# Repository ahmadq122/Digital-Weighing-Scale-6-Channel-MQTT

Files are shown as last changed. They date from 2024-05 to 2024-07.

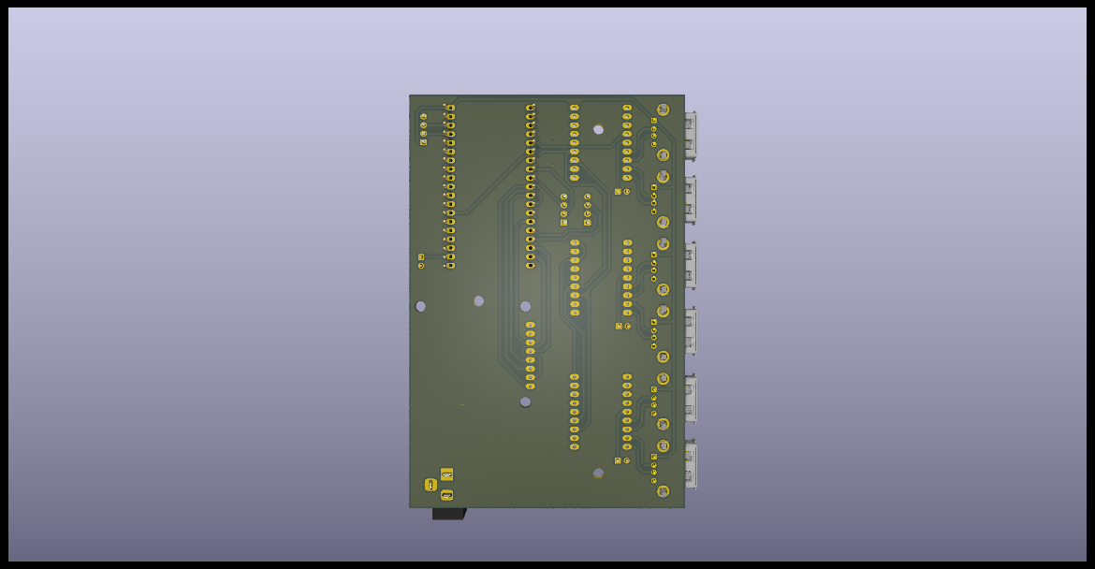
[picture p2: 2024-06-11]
kicad/kicad-weight-scale-6-ch/png/kicad-weight-scale-6-ch_bot.png

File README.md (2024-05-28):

# Digital-Weighing-Scale-Board-6-Channels-MQTT
The board uses ESP32 Dev Board as the microcontroller with Nextion 3.2" Enhanced LCD Touch as a User Interface, made in portable form, and easy to use. Real Time Operating System (FreeRTOS) was applied to get better code structure and device performance. Weighing can be performed on 6 different objects at the same time, with adjustable maximum weighing on each channel. Use 3 pcs of IC ADS1232 as an Analog to Digital Converter. Calibration sensor feature available, with a maximum of 8 calibration points. 3 data logging types are available, which are Local via Micro SD card, Serial UART, and logging through MQTT Protocol.

The code programming is done in IDE: Visual Studio Code - Platform IO, Framework: Arduino

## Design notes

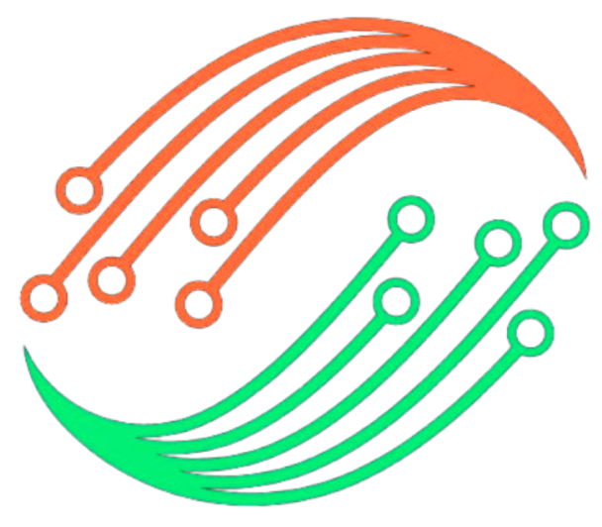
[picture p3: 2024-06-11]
kicad/kicad-weight-scale-6-ch-rev_1.1-1.0/png/kieworks_eng.png

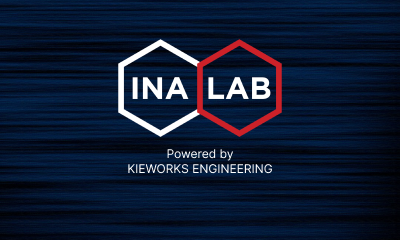
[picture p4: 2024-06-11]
hmi/start screen.png

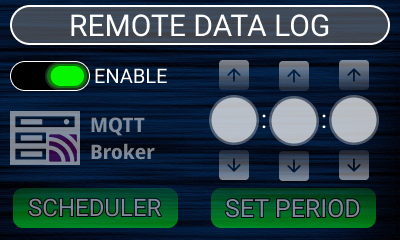
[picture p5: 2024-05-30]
hmi/Remote logger pressed.png

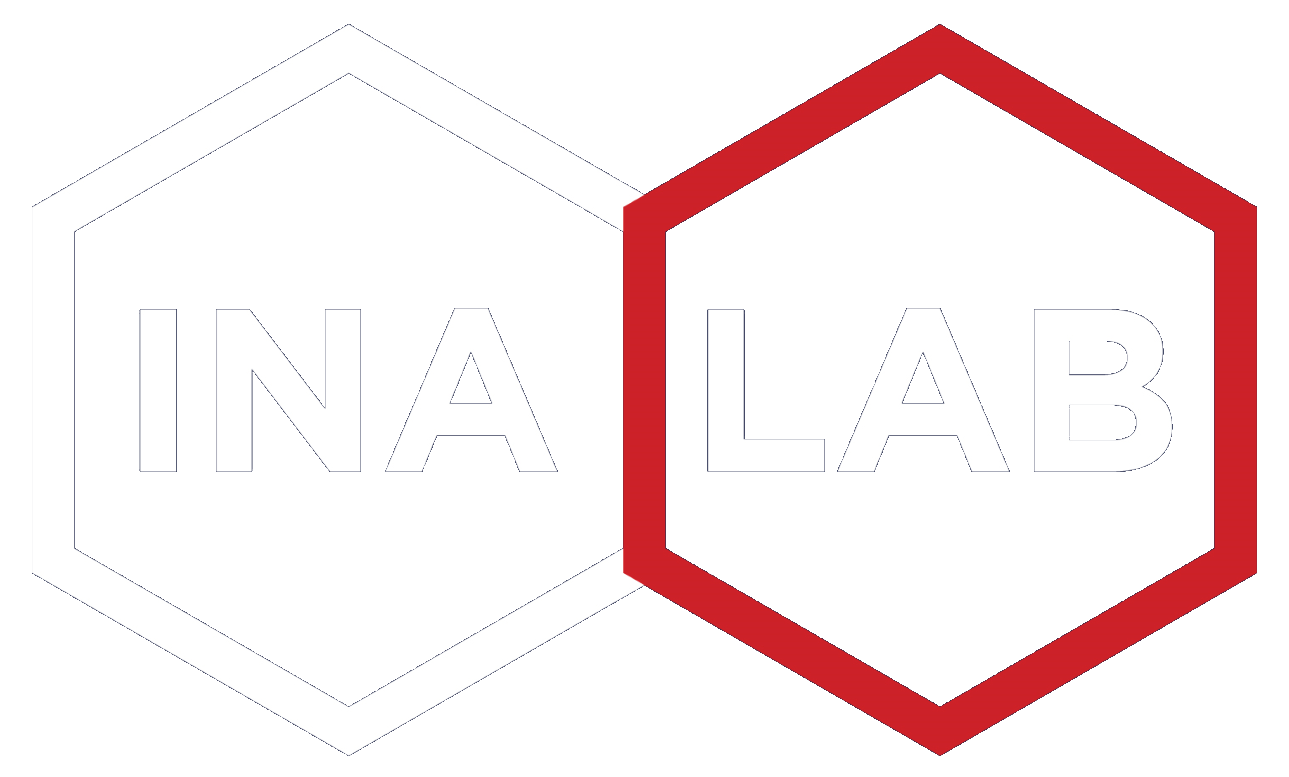
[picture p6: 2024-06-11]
kicad/kicad-weight-scale-6-ch/png/INALAB-full.png

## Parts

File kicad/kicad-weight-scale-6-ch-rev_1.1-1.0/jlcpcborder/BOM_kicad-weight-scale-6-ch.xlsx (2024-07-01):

ID | Name | Designator | Footprint | Quantity | Manufacturer Part | Manufacturer | Supplier | Supplier Part | Price | Remarks
1 | 330uF | C1 | CAP-SMD_BD6.3-L6.6-W6.6-LS7.2-FD | 1 | RST330UF10V027 | KNSCHA(科尼盛) | LCSC | C4747980 | 0.033
2 | SS14_C2986110 | D2,D1 | SMA_L4.3-W2.6-LS5.1-RD | 2 | SS14 | GOODWORK(固得沃克) | LCSC | C2986110 | 0.01
3 | DS1021-1X2SF11-B | J6,J8,J7 | HDR-TH_2P-P2.54-V-M | 3 | DS1021-1x2SF11-B | CONNFLY | LCSC | C7430358 | 0.009
4 | KH-2.54FH-1X19P-H8.5 | U3 | HDR-TH_19P-P2.54-V-F | 2 | KH-2.54FH-1X19P-H8.5 | kinghelm(金航标) | LCSC | C2932678 | 0.145 | Pair Installation
5 | JTJ-USB-AF-08 | P2,P4,P5,P6,P1,P3 | USB-A-TH__USB-AF-90 | 6 | 902-131A1011D10100 | 精拓金 | LCSC | C2345 | 0.046
6 | 47k | R4,R3 | R0805 | 2 | RC0805JR-0747KL | YAGEO(国巨) | LCSC | C131051 | 0.002
7 | DS1023-1X9SF11 | U6,U4,U2 | HDR-TH_9P-P2.54-V-F-1 | 6 | DS1023-1x9SF11 | CONNFLY | LCSC | C7509520 | 0.059 | Pair Installation
8 | 27k | R1 | R0805 | 1 | CR0805J80273G | LIZ(丽智电子) | LCSC | C101982 | 0.003
9 | Serial2 | J5 | CONN-TH_4P-P2.50_XH-4A | 1 | XH-4A | BOOMELE(博穆精密) | LCSC | C37815 | 0.012
10 | Serial1 | J4 | CONN-TH_4P-P2.50_XH-4A | 1 | XH-4A | BOOMELE(博穆精密) | LCSC | C37815 | 0.012
11 | LM2596MDT-5.0/TR | U1 | TO-263-5_L10.2-W8.9-P1.70-BR | 1 | LM2596S-5.0 | UMW(友台半导体) | LCSC | C347421 | 0.492
12 | Header-Female-2.54_1x8 | U5 | HDR-TH_8P-P2.54-V-F-1 | 1 | 2.54-1*8P母环保 | BOOMELE(博穆精密) | LCSC | C27438 | 0.074
13 | Reset | J2 | HDR-TH_2P-P2.54-V-M | 1 | DS1021-1x2SF11-B | CONNFLY | LCSC | C7430358 | 0.009
14 | 33uH | L1 | IND-SMD_L12.0-W12.0_CDRH125L125NP-470MC | 1 | PSPHAQ127-330M | PROD(谱罗德) | LCSC | C2983067 | 0.211
15 | Serial | J3 | CONN-TH_4P-P2.50_XH-4A | 1 | XH-4A | BOOMELE(博穆精密) | LCSC | C37815 | 0.012
16 | 100k | R2 | R0805 | 1 | PTFR0805B100KP9 | RESI(开步睿思) | LCSC | C478884 | 0.126
17 | 220uF | C2 | CAP-SMD_BD6.3-L6.6-W6.6-FD | 1 | 189RV0019 | KNSCHA(科尼盛) | LCSC | C7471881 | 0.087
18 | DC-005-20A | J1 | DC-IN-TH_DC005 | 1 | DC-005-20A | 韩国韩荣 | LCSC | C130239 | 0.095

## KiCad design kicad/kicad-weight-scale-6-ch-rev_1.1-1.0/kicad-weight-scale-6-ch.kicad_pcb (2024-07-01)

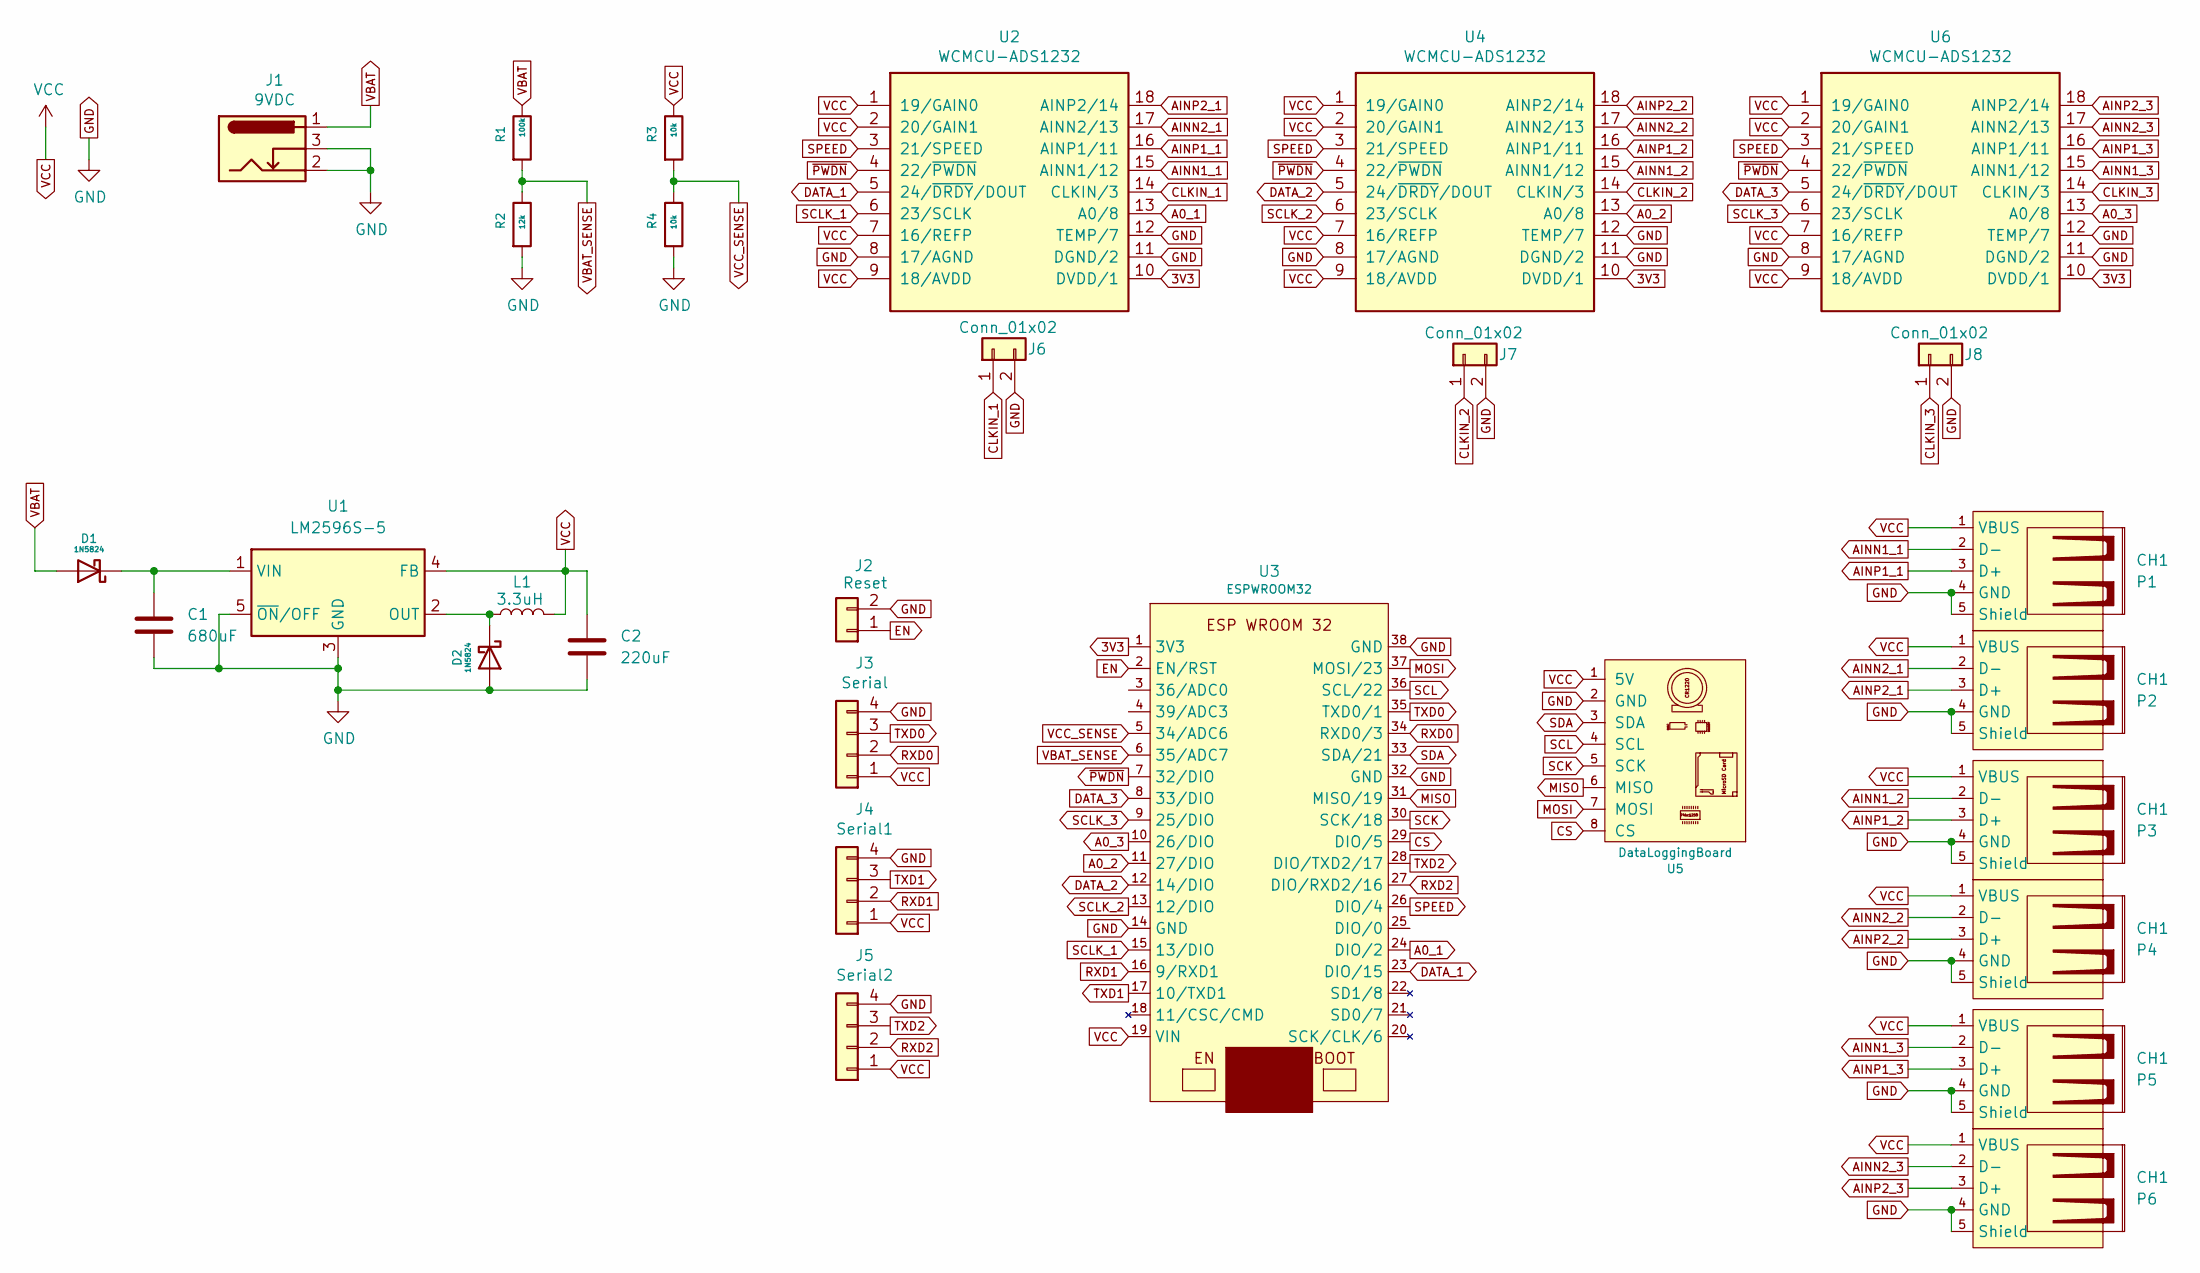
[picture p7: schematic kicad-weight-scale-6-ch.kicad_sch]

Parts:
C1: 680uF; CP_Elec_6.3x9.9
C2: 220uF; CP_Elec_6.3x9.9
D1, D2: 1N5824; D_SMA
J1: 9VDC; BarrelJack_Horizontal
J2: Reset; PinHeader_1x02_P2.54mm_Vertical
J3: Serial; JST_XH_B4B-XH-A_1x04_P2.50mm_Vertical
J4: Serial1; JST_XH_B4B-XH-A_1x04_P2.50mm_Vertical
J5: Serial2; JST_XH_B4B-XH-A_1x04_P2.50mm_Vertical
J6, J7, J8: Conn_01x02; PinHeader_1x02_P2.54mm_Vertical
L1: 3.3uH; L_12x12mm_H4.5mm
P1, P2, P3, P4, P5, P6: CH1; USB_A_CONNFLY_DS1095-WNR0
R1: 100k; R_0805_2012Metric_Pad1.20x1.40mm_HandSolder
R2: 12k; R_0805_2012Metric_Pad1.20x1.40mm_HandSolder
R3, R4: 10k; R_0805_2012Metric_Pad1.20x1.40mm_HandSolder
U1: LM2596S-5; TO-263-5_TabPin3
U2, U4, U6: WCMCU-ADS1232; wcmcu-ads1232
U3: ESPWROOM32; esp wroom 32 board
U5: DataLoggingBoard; Datalogging board

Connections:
3V3: U2.10 (DVDD/1), U3.1 (3V3), U4.10 (DVDD/1), U6.10 (DVDD/1)
A0_1: U2.13 (A0/8), U3.24 (DIO/2)
A0_2: U3.11 (27/DIO), U4.13 (A0/8)
A0_3: U3.10 (26/DIO), U6.13 (A0/8)
AINN1_1: P1.2 (D-), U2.15 (AINN1/12)
AINN1_2: P3.2 (D-), U4.15 (AINN1/12)
AINN1_3: P5.2 (D-), U6.15 (AINN1/12)
AINN2_1: P2.2 (D-), U2.17 (AINN2/13)
AINN2_2: P4.2 (D-), U4.17 (AINN2/13)
AINN2_3: P6.2 (D-), U6.17 (AINN2/13)
AINP1_1: P1.3 (D+), U2.16 (AINP1/11)
AINP1_2: P3.3 (D+), U4.16 (AINP1/11)
AINP1_3: P5.3 (D+), U6.16 (AINP1/11)
AINP2_1: P2.3 (D+), U2.18 (AINP2/14)
AINP2_2: P4.3 (D+), U4.18 (AINP2/14)
AINP2_3: P6.3 (D+), U6.18 (AINP2/14)
CLKIN_1: J6.1, U2.14 (CLKIN/3)
CLKIN_2: J7.1, U4.14 (CLKIN/3)
CLKIN_3: J8.1, U6.14 (CLKIN/3)
CS: U3.29 (DIO/5), U5.8 (CS)
DATA_1: U2.5 (24/~DRDY/DOUT), U3.23 (DIO/15)
DATA_2: U3.12 (14/DIO), U4.5 (24/~DRDY/DOUT)
DATA_3: U3.8 (33/DIO), U6.5 (24/~DRDY/DOUT)
EN: J2.1, U3.2 (EN/RST)
GND: C1.2, C2.2, D2.2 (A), J1.2, J1.3, J2.2, J3.4, J4.4, J5.4, J6.2, J7.2, J8.2, P1.4 (GND), P1.5 (Shield), P2.4 (GND), P2.5 (Shield), P3.4 (GND), P3.5 (Shield), P4.4 (GND), P4.5 (Shield), P5.4 (GND), P5.5 (Shield), P6.4 (GND), P6.5 (Shield), R2.2, R4.2, U1.3 (GND), U1.5 (~ON/OFF), U2.8 (17/AGND), U2.11 (DGND/2), U2.12 (TEMP/7), U3.14 (GND), U3.32 (GND), U3.38 (GND), U4.8 (17/AGND), U4.11 (DGND/2), U4.12 (TEMP/7), U5.2 (GND), U6.8 (17/AGND), U6.11 (DGND/2), U6.12 (TEMP/7)
MISO: U3.31 (MISO/19), U5.6 (MISO)
MOSI: U3.37 (MOSI/23), U5.7 (MOSI)
unnamed: C1.1, D1.1 (K), U1.1 (VIN)
unnamed: D2.1 (K), L1.1, U1.2 (OUT)
RXD0: J3.2, U3.34 (RXD0/3)
RXD1: J4.2, U3.16 (9/RXD1)
RXD2: J5.2, U3.27 (DIO/RXD2/16)
SCK: U3.30 (SCK/18), U5.5 (SCK)
SCL: U3.36 (SCL/22), U5.4 (SCL)
SCLK_1: U2.6 (23/SCLK), U3.15 (13/DIO)
SCLK_2: U3.13 (12/DIO), U4.6 (23/SCLK)
SCLK_3: U3.9 (25/DIO), U6.6 (23/SCLK)
SDA: U3.33 (SDA/21), U5.3 (SDA)
SPEED: U2.3 (21/SPEED), U3.26 (DIO/4), U4.3 (21/SPEED), U6.3 (21/SPEED)
TXD0: J3.3, U3.35 (TXD0/1)
TXD1: J4.3, U3.17 (10/TXD1)
TXD2: J5.3, U3.28 (DIO/TXD2/17)
VBAT: D1.2 (A), J1.1, R1.1
VBAT_SENSE: R1.2, R2.1, U3.6 (35/ADC7)
VCC: C2.1, J3.1, J4.1, J5.1, L1.2, P1.1 (VBUS), P2.1 (VBUS), P3.1 (VBUS), P4.1 (VBUS), P5.1 (VBUS), P6.1 (VBUS), R3.1, U1.4 (FB), U2.1 (19/GAIN0), U2.2 (20/GAIN1), U2.7 (16/REFP), U2.9 (18/AVDD), U3.19 (VIN), U4.1 (19/GAIN0), U4.2 (20/GAIN1), U4.7 (16/REFP), U4.9 (18/AVDD), U5.1 (5V), U6.1 (19/GAIN0), U6.2 (20/GAIN1), U6.7 (16/REFP), U6.9 (18/AVDD)
VCC_SENSE: R3.2, R4.1, U3.5 (34/ADC6)
~PWDN: U2.4 (22/~PWDN), U3.7 (32/DIO), U4.4 (22/~PWDN), U6.4 (22/~PWDN)

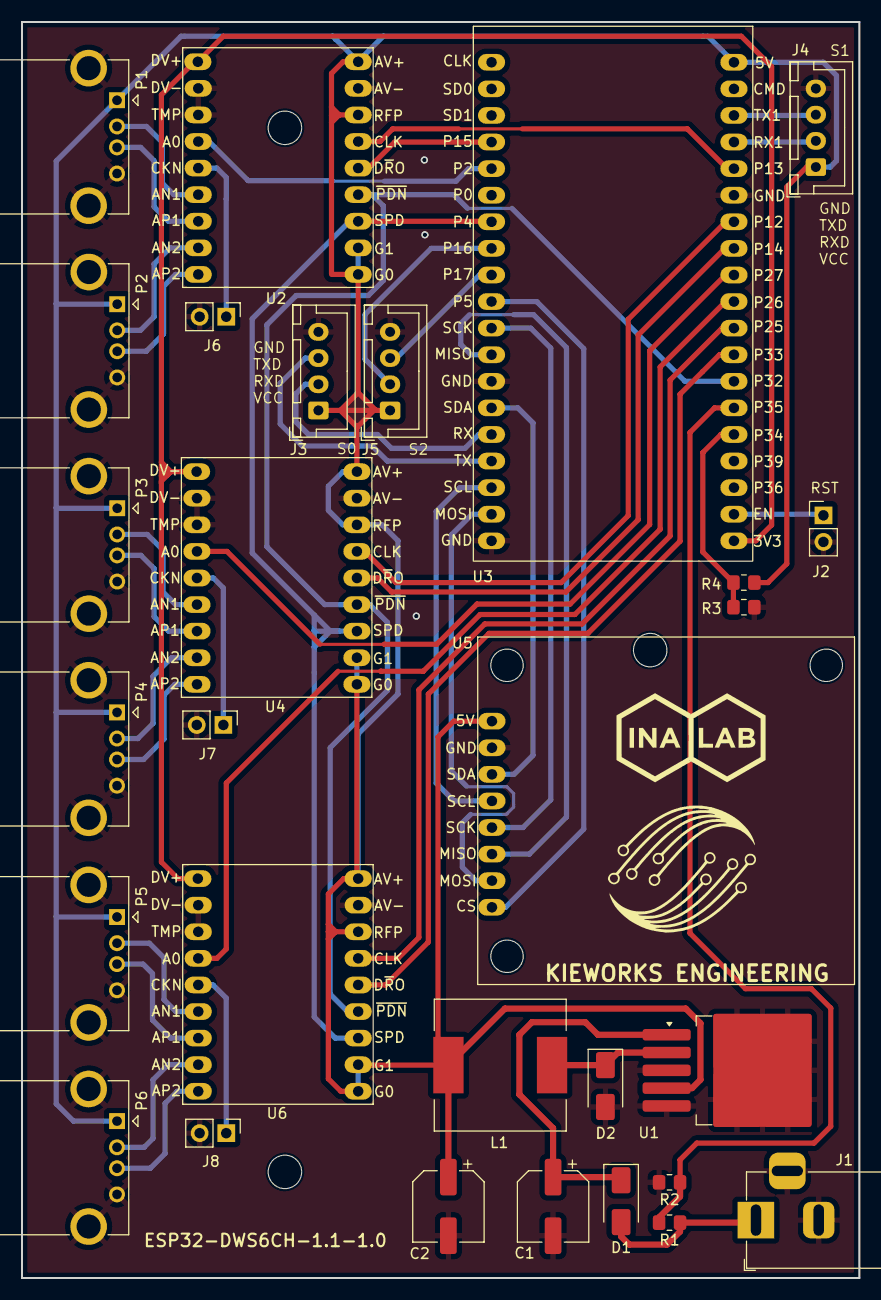
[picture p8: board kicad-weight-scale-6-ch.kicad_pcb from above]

Board: 2 copper layers, 80.0 x 120.0 mm, 29 parts (0 on the bottom side), 47 nets.

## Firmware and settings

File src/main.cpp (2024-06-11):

#include "StateMachine/StateMachine.h"
#include "FlashMemory/FlashMemory.h"
#include "Utility/Utility.h"
// #include "PublisherSubscriber/PublisherSubscriber.h"

StateMachine *state = new (StateMachine);

void setup()
{
  // put your setup code here, to run once:
  state->setup();
}

void loop()
{
  // // put your main code here, to run repeatedly:
  // MemoryFlash d;
  // Serial.println(String() + "uint8_t:" + sizeof(uint8_t));
  // Serial.println(String() + "uint16_t:" + sizeof(uint16_t));
  // Serial.println(String() + "uShort:" + sizeof(unsigned short));
  // Serial.println(String() + "uint32_t:" + sizeof(uint32_t));
  // Serial.println(String() + "uint:" + sizeof(unsigned int));
  // Serial.println(String() + "uLong:" + sizeof(unsigned long));
  // Serial.println(String() + "float:" + sizeof(float));
  // Serial.println(String() + "double:" + sizeof(double));
  // Serial.println(String() + "uint64_t:" + sizeof(uint64_t));
  // // Serial.end();
  // // Serial.begin(115200);
  // delay(1000);
  // uint8_t sizeLeft = MEMORY_SIZE - sizeof(d.flash);
  // uint16_t size = sizeof(d.flash);
  // Serial.println(size);
  // Serial.println(String() + "Free memory: " + sizeLeft + " bytes");

  uint8_t nextState = HOME;

  while (true)
  {
    nextState = state->homeScreen();

    switch (nextState)
    {
    case NETWORK:
      state->networkSettings();
      break;
    case SETTINGS:
      state->settings();
      break;
    case UNITS:
      state->measurementUnits();
      break;
    case DATALOG:
      state->datalogSettings();
      break;
    default:
      break;
    }
  }
}

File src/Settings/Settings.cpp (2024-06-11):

#include "Settings.h"
#include "Nextion/Nextion.h"
#include "FlashMemory/FlashMemory.h"
#include "Time/MyTime.h"
#include "RTOS/RTOS.h"
#include "ADC/ADS1232.h"
#include "PictureListID.h"
#include "Utility/Utility.h"
#include "PinMap.h"

void Settings::mainMenu(void)
{
    bool button[8];
    bool adcRateValue = fdata->getSpeedRate();
    bool mute = fdata->getBuzzerMute();
    uint8_t menuPage = 0;

start:

    if (menuPage == 0)
    {
        hmi->showPage("settings");
        hmi->waitForPageRespon();
    }
    else
    {
        hmi->showPage("settings1");
        hmi->waitForPageRespon();
        if (adcRateValue && fdata->getSpeedRate())
        {
            hmi->setIntegerToNextion("b0.picc", Settings1_Menu_Normal_Btn);
            hmi->setIntegerToNextion("b0.picc2", Settings1_Menu_Prs_Btn);
        }
        else
        {
            if (adcRateValue != fdata->getSpeedRate())
                adcRateValue = fdata->getSpeedRate();
            hmi->setIntegerToNextion("b0.picc", Settings11_Menu_Normal_Btn);
            hmi->setIntegerToNextion("b0.picc2", Settings11_Menu_Prs_Btn);
        }
        if (mute && fdata->getBuzzerMute())
        {
            hmi->setIntegerToNextion("b2.picc", Settings11_Menu_Normal_Btn);
            hmi->setIntegerToNextion("b2.picc2", Settings11_Menu_Prs_Btn);
        }
        else
        {
            if (mute != fdata->getBuzzerMute())
                mute = fdata->getBuzzerMute();
            hmi->setIntegerToNextion("b2.picc", Settings1_Menu_Normal_Btn);
            hmi->setIntegerToNextion("b2.picc2", Settings1_Menu_Prs_Btn);
        }
    }
    // Serial.println("Settings page opened");

    while (true)
    {
        // hmi->serialEvent_2();
        if (hmi->getExitPageFlag())
        {
            // Serial.println("Exit Settings page");
            return;
        }
        for (int i = 0; i < 8; i++)
        {
            button[i] = hmi->getDataButton(i);
            if (button[i])
            {
                switch (i)
                {
                case 0:
                    if (menuPage == 0)
                    {
                        // Serial.println("Timezone page opened");
                        timeZone();
                    }
                    else if (menuPage == 1)
                    {
                        // Serial.println("ADC Rate value changed");
                        adcRateValue = !adcRateValue;
                        fdata->setSpeedRate(adcRateValue);
                        hmi->showSavingBarAnimation(1000);
                    }
                    break;
                case 1:
                    // Serial.println("Brightness page opened");
                    if (menuPage == 0)
                        brightness();
                    else if (menuPage == 1)
                    {
                        hmi->setVisObjectNextion("q0", true);
                        hmi->setVisObjectNextion("b8", true);
                        hmi->setVisObjectNextion("b9", true);

                        while (true)
                        {
                            if (hmi->getExitPageFlag())
                            {
                                // Serial.println("Exit Settings page");
                                return;
                            }
                            if (hmi->getDataButton(8))
                            {
                                break;
                            }
                            if (hmi->getDataButton(9))
                            {
                                if (fdata->resetDefault())
                                    hmi->showSavingBarAnimation(250);
                                break;
                            }
                        }

                        hmi->setVisObjectNextion("b8", false);
                        hmi->setVisObjectNextion("b9", false);
                        hmi->setVisObjectNextion("q0", false);
                        hmi->flushAvailableButton();
                    }
                    break;
                case 2:
                    // Serial.println("Maximum page opened");
                    if (menuPage == 0)
                        setLimit();
                    else
                    {
                        mute = !mute;
                        fdata->setBuzzerMute(mute);
                        hmi->showSavingBarAnimation(500);
                    }
                    break;
                case 3:
                    // Serial.println("Set time and date");
                    if (menuPage == 0)
                        timeAndDate();
                    break;
                case 4:
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

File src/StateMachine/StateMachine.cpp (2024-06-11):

#include <Arduino.h>
#include "StateMachine.h"
#include "FlashMemory/FlashMemory.h"
#include "Nextion/Nextion.h"
#include "Network/Network.h"
#include "Time/MyTime.h"
#include "MicroSD/MicroSD.h"
#include <HTTPClient.h>
#include "Settings/Settings.h"
#include "ADC/ADS1232.h"
#include "RTOS/RTOS.h"
#include "Datalogger/Datalogger.h"
#include "PinMap.h"
#include "PictureListID.h"
#include "Utility\Utility.h"
#include "PublisherSubscriber/PublisherSubscriber.h"

/*****************************************************************************
 *******************************ESP32S-PIN************************************
 *                  ---------------------------------
 *              ---|3.3V     ---__---__-----      GND|---
 *              ---|EN/RST  |            | |       23|---VSPI_MOSI
 *            AI---|36       _______________       22|---SCL
 *            AI---|39      |               |       1|---TX0
 *            AI---|34      | ESP-WROOM-32  |       3|---RX0
 *            AI---|35      |               |      21|---SDA
 *           DIO---|32      |               |     GND|---
 *           DIO---|33      |               |      19|---VSPI_MISO
 *           DIO---|25      |_______________|      18|---VSPI_SCK
 *           DIO---|26                              5|---DIO
 *           DIO---|27                             17|---TX2
 *           DIO---|14                             16|---RX2
 *           DIO---|12                             -4|---DIO
 *              ---|GND                            -0|---DIO
 *           DIO---|13                              2|---DIO
 *           RX1---|9                              15|---DIO
 *           TX1---|10           _______            8|---SD1*
 *      *CSC/CMD---|11   ___    |       |    ____   7|---SD0*
 *              ---|Vin |EN |   |       |   |BOOT|  6|---SCK/CLK*
 *                  ------------|_______|------------
 *
 *          *Pins are connected to the integrated SPI Flash integrated on
 *           ESP-32 and are not recommended for other uses.
 ******************************************************************************/

// 36,//can't be used as output pin
// 39,////can't be used as output pin
// 34,//can't be used as output pin
// 35,//can't be used as output pin
// 9,
// 10,
// 11,6,7,8
// uint8_t pin[10] = {
//     12,
//     13,
//     15,
//     2,
//     32,
//     33,
//     25,
//     26,
//     27,
//     14};

void StateMachine::setup(void)
{
    uint8_t powerUpButtonWait = 2;
    bool flashBegin = false;
    uint8_t counter = 0;

    // pinMode(Pin_Buzzer, OUTPUT);
    // digitalWrite(Pin_Buzzer, 0);

    while (powerUpButtonWait > 0)
    {
        delay(1000);
        powerUpButtonWait--;
    }

    Serial.begin(115200);
    NexSerial.begin(115200);
    while (!NexSerial)
        ;
    hmi->showPage("start");
    // waiting for Nextion page ready
    while (!hmi->getWaitingEndSignal())
    {
        hmi->serialEvent_2();
        delay(100);
        if (++counter > 10)
        {
            hmi->showPage("start"); // call back start page if still no respons from LCD
            counter = 0;
        }
    }
    // Serial.end();

    rtos->updateStartProgressBar(5);
    while (flashBegin == false)
    {
        flashBegin = initFlash(MEMORY_SIZE);
        delay(200);
    }
    delay(10);

    rtos->updateStartProgressBar(5);

    // Serial.println("Serial begin");
    // Serial.println(String() + "debug mode " + fdata->getDebugMode() + " " + fdata->getBaudrateSerial(debugging));
    if (fdata->getDebugMode())
    {
        Serial.begin(fdata->getBaudrateSerial(debugging));
        while (!Serial)
            ;
    }
    else
    {
    }
    LogSerial.begin(fdata->getBaudrateSerial(logging));
    while (!LogSerial)
        ;

    rtos->updateStartProgressBar(5);
    ads->begin();
    rtos->setup();
    rtos->updateStartProgressBar(5);
    net->setup();
    initTime();
    rtos->updateStartProgressBar(5);
    hmi->init();
    sdcard->setup();
    rtos->updateStartProgressBar(5);
    pubSubs->setup();

    while (rtos->startProgressBar < 100)
    {
        // Serial.println(String() + "Progress: " + rtos->startProgressBar + " %");
        rtos->updateStartProgressBar(5);
        delay(50);
    }

    // digitalWrite(Pin_Buzzer, 1);
    // delay(100);
    // digitalWrite(Pin_Buzzer, 0);
}

bool StateMachine::initTime(void)
{
    mtime.initOffset(fdata->getTimezone());
    return mtime.tBegin();
}

bool StateMachine::initFlash(uint16_t memory)
{
    if (memory > MEMORY_SIZE)
        return false;
    return fdata->begin(memory);
}

// void StateMachine::initSDCard(void)
// {
//     sdcard->setup();
// }

/******************
 * List of Button at HomeScreen
 * 0) Network
 * 1) Settings
 * 2) Measurement Units
 * 3) Data logger
 * 4) EN/DIS Channel 1
 * 5) EN/DIS Channel 2
 * 6) EN/DIS Channel 3
 * 7) EN/DIS Channel 4
 * 8) EN/DIS Channel 5
 * 9) EN/DIS Channel 6
 * 10) Tare Channel 1
 * 11) Tare Channel 2
 * 12) Tare Channel 3
 * 13) Tare Channel 4
 * 14) Tare Channel 5
 * 15) Tare Channel 6
 */
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

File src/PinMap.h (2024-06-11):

#pragma once

#define Pin_PowerDown   32
#define Pin_SCLK_ADS2   12
#define Pin_SCLK_ADS1   13
#define Pin_SCLK_ADS3   25
#define Pin_DOUT_ADS2   14
#define Pin_DOUT_ADS1   15
#define Pin_DOUT_ADS3   33
#define Pin_A0_ADS2     27
#define Pin_A0_ADS1     2
#define Pin_A0_ADS3     26

#define Pin_Speedrate   4

#define Pin_VBat_Sense  35
#define Pin_Buzzer      0  // also used as Boot PIN, not recommended to use this PIN as DIO

#define Pin_VCC_Sense   34

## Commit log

2024-05-29 Remove vcc contrl & buzzer, update stack size, 2 type off req
    [Datalogger.cpp, PinMap.h, RTOS.cpp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]
2024-06-11 , String to char*, Receive server setup from display
    [kicad-weight-scale-6-ch-B_Cu.gbl, kicad-weight-scale-6-ch-B_Fab.gbr, kicad-weight-scale-6-ch-B_Mask.gbs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]
2024-07-01 Update PCB file and place an order to JLCPCB
    [BOM_kicad-weight-scale-6-ch.xlsx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]
2024-07-02 Add option to use 8MB flash memory
    [default_8MB.csv]
